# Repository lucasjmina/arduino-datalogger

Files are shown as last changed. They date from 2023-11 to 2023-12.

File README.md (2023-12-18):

# Arduino based datalogger




Enviroment variables are important for ecological studies because they affect the life cicle and
behaviour of organisms. Obtaining a trustworthy record of these variables require the use of
dataloggers, that can be quite expensive.  
Our objective is developing a datalogger more accesible and versatile than comercial available ones,
this could allow an increase in the data volume or making available a trustworthy way of recording
enviromental variables for small investigation groups.  
This repository corresponds to the first prototipe, codename "Oreo".

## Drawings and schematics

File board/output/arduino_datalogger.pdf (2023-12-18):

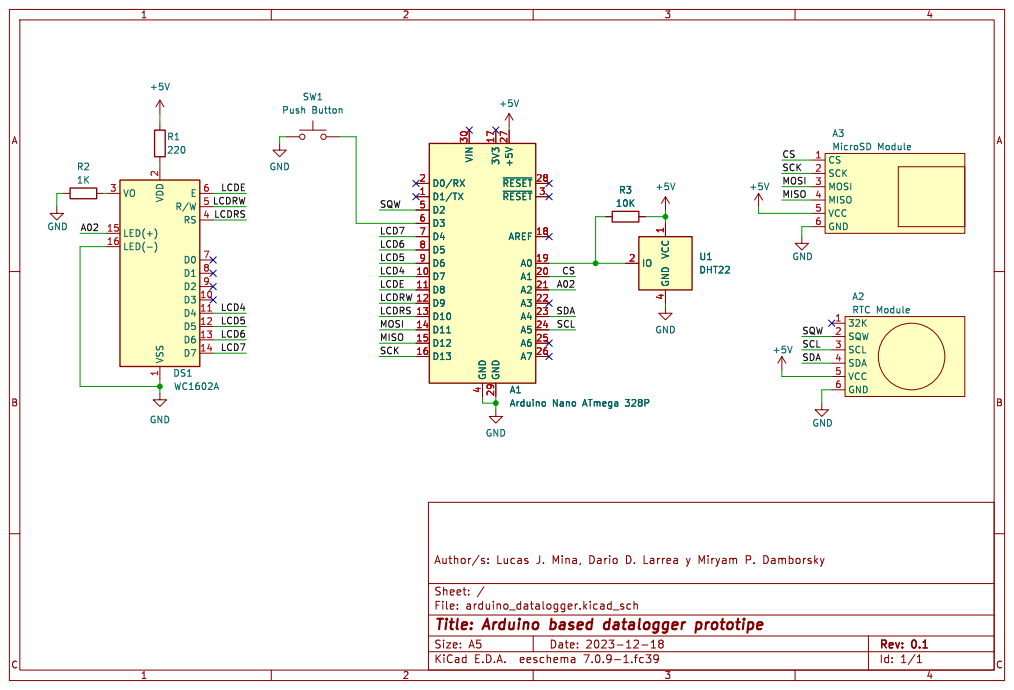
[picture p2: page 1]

SW1 Push Button GND VSS

4 A1Arduino Nano ATmega 328P D1/TX 1 D7 10 D8 11 D9 12 D10 13 D11 14 D12 15 D13 16 3V3 17 AREF 18 A0 19 D0/RX 2 A1 20 A2 21 A3 22 A4 23 A5 24 A6 25 A7 26 +5V 27

Id: 1/1 Title: Arduino based datalogger prototipe

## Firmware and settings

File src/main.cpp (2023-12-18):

/*
 * main.cpp
 * Author/s: Lucas J. Mina. Dario D. Larrea & Miriam P. Damborsky
 * Description: Code for a humidity and temperatura detalogger prototipe using a DHT sensor and
 * Arduino. Codename "Oreo".
 * 
 * TODO:
 * - Sleep "better" for more energy saving https://www.gammon.com.au/power
 * - Set a limit for measurement using a counter or date/time (RTC's alarm 2 maybe?)
 * - Find a way to check that sensors and other modules are connected and working correctly.
 */

#include <Arduino.h>
#include <Wire.h>
#include <RTClib.h>
#include <LiquidCrystal.h>
#include <DHT.h>
#include <SdFat.h>
#include <SPI.h>
#include <avr/sleep.h>

//1 for sincronizing RTC time with system's
#define set_time 0

//LCD pins definition
#define rs 10
#define rw 9
#define en 8
#define d4 7
#define d5 6
#define d6 5
#define d7 4

#define dht_pin 14
#define int_pin 2
#define sd_pin 15
#define bclk_pin 16
#define button_pin 3

//Measurement taking interval (days, hours, minutes, seconds)
TimeSpan interval = TimeSpan(0, 0, 1, 0);
int count = 1;
DateTime time_now;
float tt;
float hh;
unsigned long previous_millis;
volatile bool write = false;
volatile bool lcd_on = false;
char filename[27] = "YYYYMMDDhhmmss_DATALOG.csv";

LiquidCrystal lcd(rs, rw, en, d4, d5, d6, d7);
DHT dht(dht_pin, DHT22);
RTC_DS3231 rtc;
SdFat SD;

void int00_isr() {
    sleep_disable();
    write = true;
}

void int01_isr() {
    sleep_disable();
    lcd_on = true;
}

void sleep_time() {
    noInterrupts();
    set_sleep_mode(SLEEP_MODE_PWR_DOWN);
    sleep_enable();
    interrupts();
    sleep_cpu();
}

void setup() {
    pinMode(bclk_pin, OUTPUT);
    digitalWrite(bclk_pin, HIGH);
    lcd.begin(16, 2);
    dht.begin();
    rtc.begin();

#if set_time == 1
    rtc.adjust(DateTime(F(__DATE__), F(__TIME__)));
#endif

    if (!SD.begin(sd_pin)) {
        lcd.print("SD?");
        while(1);
    }

    //Unique name for new files using timestamp (YYYYMMDDhhmmss_DATALOG.csv)
    time_now = rtc.now();
    time_now.toString(filename);

    //CSV header
    File datalog = SD.open(filename, FILE_WRITE);
    datalog.println("number,date,time,temperature,humidity");
    datalog.close();

    //When "off" SQW pin is normally high and goes low when alarm "rings"
    rtc.writeSqwPinMode(DS3231_OFF);
    //Making sure no alarms are set
    rtc.disableAlarm(1);
    rtc.disableAlarm(2);
    rtc.clearAlarm(1);
    rtc.clearAlarm(2);
    //Time interval for first measurement after powering on. Following measurements
    //use the time from variable "interval"
    rtc.setAlarm1(rtc.now() + TimeSpan(0, 0, 0, 3), DS3231_A1_Second);
    
    pinMode(int_pin, INPUT_PULLUP);
    pinMode(button_pin, INPUT_PULLUP);
    //FALLING mode so interrupt doesn't trigger when turning off the alarm
    attachInterrupt(digitalPinToInterrupt(int_pin), int00_isr, FALLING);
    attachInterrupt(digitalPinToInterrupt(button_pin), int01_isr, FALLING);
    
}

void loop() {
    if (write) {
        time_now = rtc.now();
        tt = dht.readTemperature();
        hh = dht.readHumidity();
        rtc.disableAlarm(1);
        rtc.clearAlarm(1);
        rtc.setAlarm1(time_now + interval, DS3231_A1_Second);

        File datalog = SD.open(filename, FILE_WRITE);
        datalog.print(count);
        datalog.print(",");
        datalog.print(time_now.timestamp(DateTime::TIMESTAMP_DATE));
        datalog.print(",");
        datalog.print(time_now.timestamp(DateTime::TIMESTAMP_TIME));
        datalog.print(",");
        datalog.print(tt);
        datalog.print(",");
        datalog.println(hh);
        datalog.close();

        write = false;
        count++;
    }

    if (lcd_on) {
        tt = dht.readTemperature();
        hh = dht.readHumidity();
        lcd.setCursor(0, 0);
        lcd.print("T: ");
        lcd.print(tt);
        lcd.print(" C");
        lcd.setCursor(0, 1);
        lcd.print("H: ");
        lcd.print(hh);
        lcd.print(" %");
        digitalWrite(bclk_pin, HIGH);
        previous_millis = millis();
        lcd_on = false;
    }
    else if (millis() - previous_millis >= 3000) {
        digitalWrite(bclk_pin, LOW);
    }
    //Do NOT suspend MCU if LCD backlight is on or there are pending measurements
    if (digitalRead(bclk_pin) == LOW && write == false) {
        sleep_time();
    }
}

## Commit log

2023-10-10 Cambios para Arduino Nano
2023-10-11 Botón para prender LCD y cambios en interrupts
    Botón enciende el balcklight del lcd y lo apaga después de un tiempo. Resulta que no se puede leer los valores del DHT dentro de un interrupt, así que eso pasó a estar dentro de loop, el interrupt so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
2023-10-12 Solucionado posible problema con el overflow de millis()
2023-10-12 Ahora se suspende durante inactividad
    Falta medir el consumo
2023-10-12 Agregado un condicional para chequear si el archivo existe o no
    Si existe se detiene el programa
2023-10-14 Cambios en la declaracion de algunas variables. Cadigo de la función 'write_sd()' movido a loop y eliminada esa función
2023-10-23 Esquema circuito
    [arduino_datalogger.kicad_pcb, arduino_datalogger.kicad_sch]
2023-10-24 Algunos cambios esquema
    [arduino_datalogger.kicad_sch]
2023-10-24 Diseñando PCB
    [arduino_datalogger.kicad_pcb]
2023-10-24 Teniendo en cuenta las medidas reales de los modulos
    [arduino_datalogger.kicad_pcb, arduino_datalogger.kicad_sch]
2023-10-25 Simbolo y footprint para modulo RTC y lector de SD
2023-10-25 Eliminado el uso de pin 13 como salida
    No me di cuenta que estaba usando el pin 13, que es el mismo que se usa
    para SPI, como salida para un led de testigo.
2023-11-06 Simbolos y footprints para modulo RTC y microSD
    [arduino_datalogger.kicad_sch]
2023-11-06 Preparando gitignore para migrar a PlatformIO
2023-11-06 Inicializando proyecto de PlatformIO
    https://platformio.org/
2023-11-06 Eliminado PCB y footprints personalizadas
    Decidimos hacer el prototipo en perfboard, así que ya no es necesario lo anterior
    [arduino_datalogger.kicad_pcb, arduino_datalogger.kicad_sch]
2023-11-06 Arreglando definición de función 'sleep_time()'
    [main.cpp]
2023-11-10 Algunos cambios en el primer bloque de comentarios
2023-11-10 Corregidas conexiones de LCD
    VO estaba conectado a Vcc con una R de 220 (debe ir a GND con R de 1K).
    Vss tenia una R de 1K (debe tener una de 220).
    [arduino_datalogger.kicad_sch]
2023-11-13 Cambio nombre de carpeta 'schematics' a 'board'
    [arduino_datalogger.kicad_sch]
2023-11-17 Movido proyecto a carpeta 'prototipo'
    [arduino_datalogger.kicad_sch]
2023-11-17 Hojas de datos relevantes
2023-12-02 Documentación
    Hojas de datos y diagramas de pines
2023-12-02 Cambio de nombre
2023-12-02 Cambios menores en esquema y generado PDF
    [arduino_datalogger.kicad_sch]
2023-12-02 Cambios en encabezado, agregado directiva de compilación para hora del RTC
2023-12-03 Cambio de carpeta
    [arduino_datalogger.kicad_sch]
2023-12-07 feat: Nombre de archivo único
    Generación de un archivo único cada vez que se inicia, utilizando un
    timestamp generado por el RTC. De la siguiente forma
    "YYYMMDDhhmmss_DATALOG.csv".
2023-12-18 refactor: Cambiada libreria para SD
    arduino-libraries/SD cambiada por greiman/SdFat.
2023-12-18 Makefile para más comodidad
2023-12-18 refactor: Added newline
    I forgot the double space 🤡
2023-12-18 Traslation of schematic to English
    [arduino_datalogger.kicad_sch]
